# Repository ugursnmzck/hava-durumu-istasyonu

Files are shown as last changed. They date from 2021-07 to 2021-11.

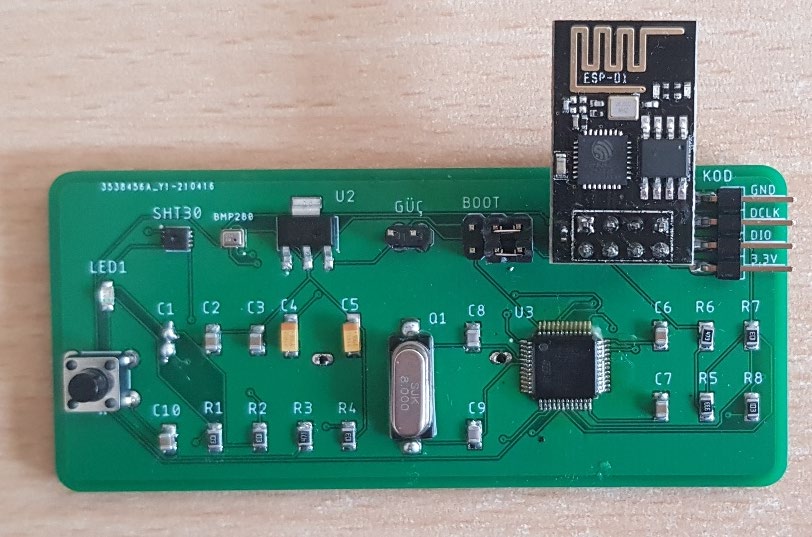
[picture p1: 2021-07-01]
Resimler/lehimli devre.jpg

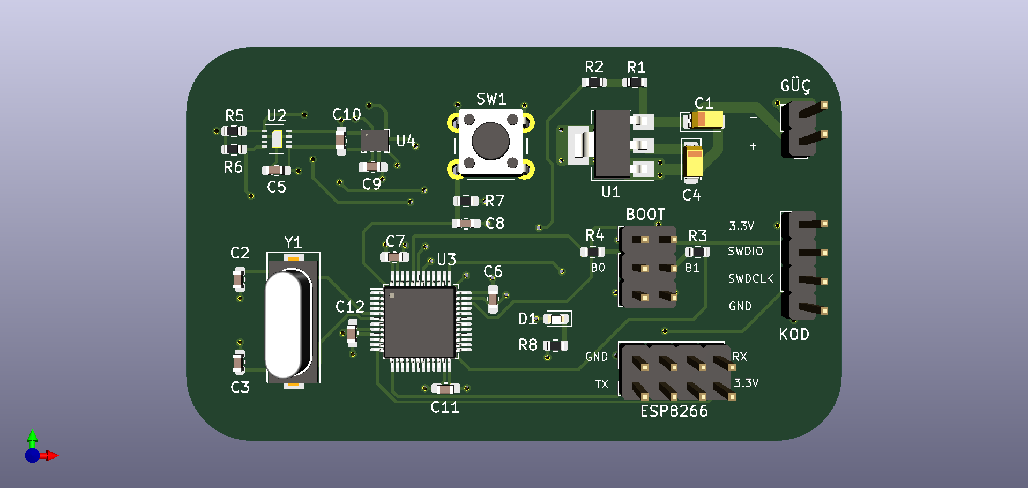
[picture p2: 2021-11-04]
Resimler/Hava_ist_v2.0.png

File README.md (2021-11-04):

# Hava Durumu İstasyonu

V2.0 Yapılan Değişiklikler:
- CAD yazılımı olarak Autodesk Eagle bırakılarak KiCAD kullanıldı.
- Mikroişlemci devresinde dijital güç girişlerinin tamamına filtre kondansatörü eklendi.
- Sıcaklık sensörünün çalışmasını engelleyen filtre kondansatörüne ait bağlantı hatası düzeltildi.
- PCB 4 katmanlı olarak yeniden tasarlandı.

V1.0:

Sıcaklık, nem ve basınç verileri sensörler yardımıyla okunarak kablosuz bir şekilde bilgisayara iletilmektedir.

Sıcaklık ve nem sensörü olarak SHT30, basınç sensörü olarak ise BMP280 kullanılmıştır. Mikrodenetleyici olarak STM32F103C8T6 tercih edilmiştir. Sensör verilerinin yanında pil geirlimi ve gerçek zamanlı saat verisi de mikrodenetleyici ile oluşturulmaktadır. Kablosuz haberleşme için ESP8266-01 modülü tercih edilmiştir. Gömülü sistem kodları C dilinde STM32 CubeIDE üzerinde yazılmıştır. Grafik arayüzü Visual Studio üzerinde C# dili ile hazırlanmıştır. Arayüz tasarımında .NET Framework ve SimpleTCP eklentisi gereklidir.

Gerekli PCB tasarımı Autodesk Eagle ile yapılmıştır.

Proje elektrik elektronik mühendisliği lisans bitirme projesi olarak tasarlanmıştır.

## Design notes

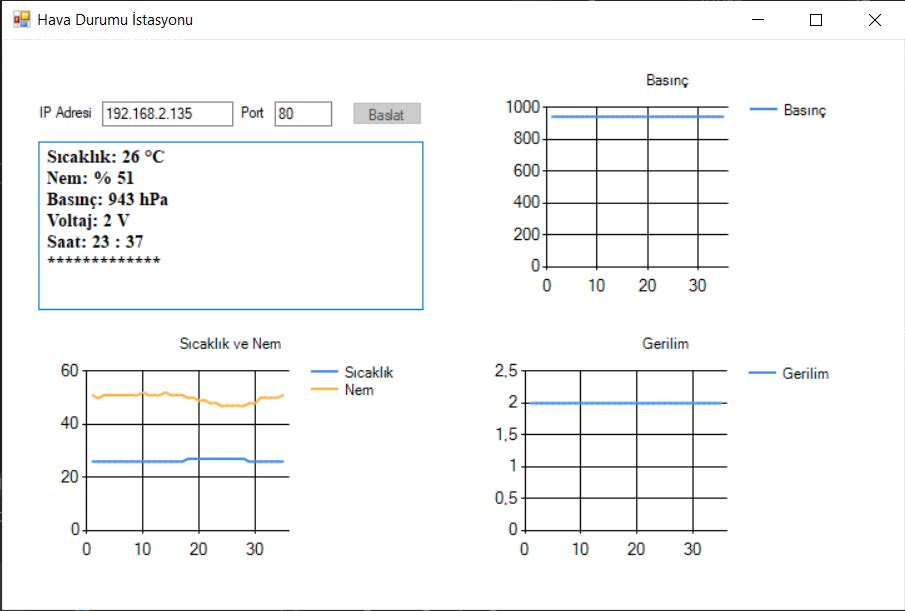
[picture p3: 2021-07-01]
Resimler/grafik arayüzü.jpg

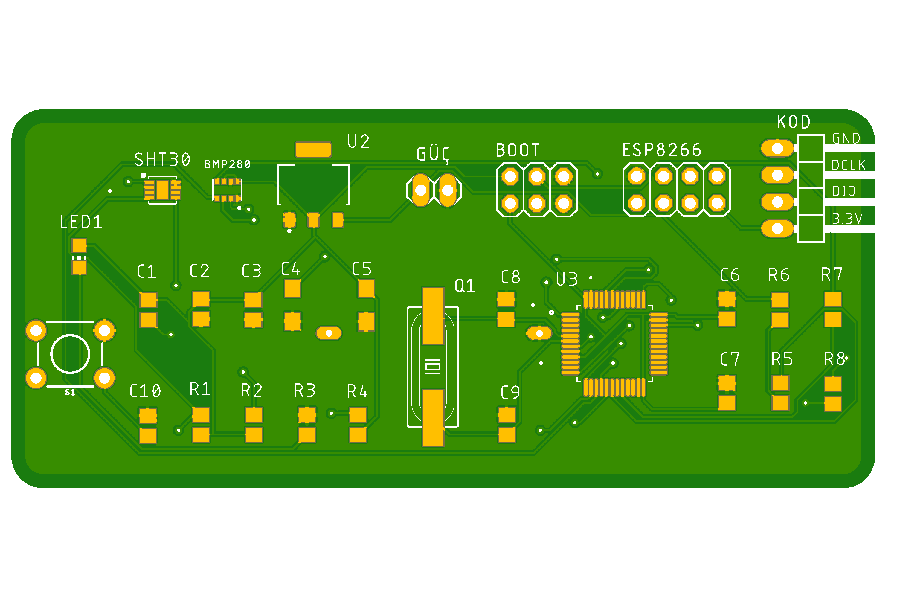
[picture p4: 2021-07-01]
Resimler/V1.0/Hava Durumu İst V1.0.png

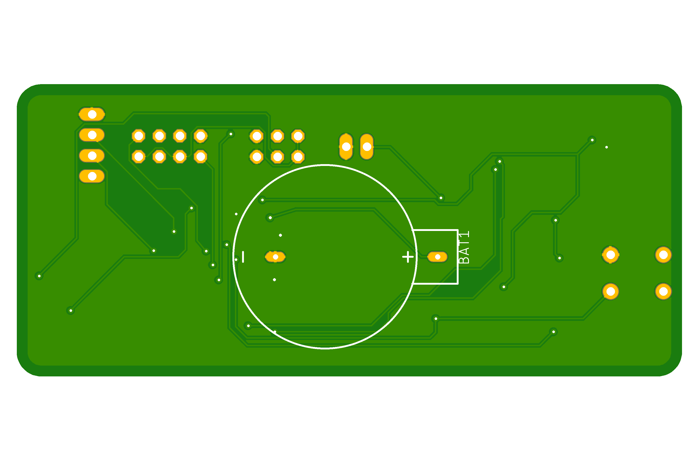
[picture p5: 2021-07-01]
Resimler/V1.0/Hava Durumu İst V1.0arka.png

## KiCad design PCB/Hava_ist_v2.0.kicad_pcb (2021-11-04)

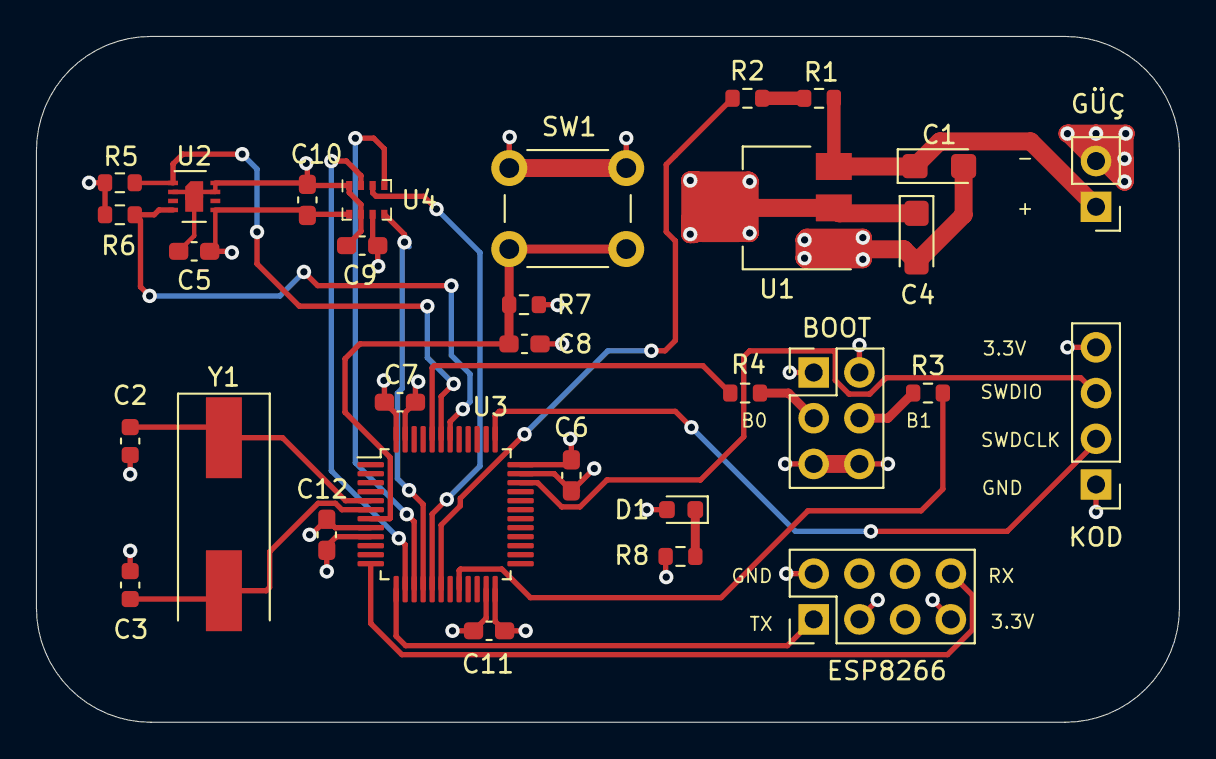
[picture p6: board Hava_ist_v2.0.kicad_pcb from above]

Board: 4 copper layers, 63.5 x 38.1 mm, 31 parts (0 on the bottom side), 23 nets.

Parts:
BOOT: 2x3; PinHeader_2x03_P2.54mm_Vertical
C1, C4: 10 uF; CP_EIA-3216-18_Kemet-A
C2, C3: 12 pF; C_0603_1608Metric
C5, C6, C7, C8, C9, C10, C11, C12: 100 nF; C_0603_1608Metric_Pad1.08x0.95mm_HandSolder
D1: LED; LED_0603_1608Metric
ESP8266: 2x4; PinHeader_2x04_P2.54mm_Vertical
GÜÇ: 1x2; PinHeader_1x02_P2.54mm_Vertical
KOD: 1x4; PinHeader_1x04_P2.54mm_Vertical
R1, R2: 50k; R_0603_1608Metric
R3, R4: 100k; R_0603_1608Metric
R5, R6, R7: 10k; R_0603_1608Metric
R8: 510 R; R_0603_1608Metric
SW1: SW_Push; SW_PUSH_6mm
U1: AMS1117-3.3; SOT-223-3_TabPin2
U2: SHT30-DIS; Sensirion_DFN-8-1EP_2.5x2.5mm_P0.5mm_EP1.1x1.7mm
U3: STM32F103C8Tx; LQFP-48_7x7mm_P0.5mm
U4: BMP280; Bosch_LGA-8_2x2.5mm_P0.65mm_ClockwisePinNumbering
Y1: 8 MHz; Crystal_SMD_HC49-SD

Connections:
+3V3: BOOT.1, BOOT.2, C4.1, C5.2, C6.1, C7.1, C9.1, C10.1, C11.1, C12.1, D1.2, ESP8266.3, ESP8266.7, KOD.4, R5.1, R6.1, R7.1, U1.2, U2.5, U3.9, U3.24, U3.36, U3.48, U4.6, U4.8
/BOOT0: BOOT.3, R4.2
/BOOT1: BOOT.4, R3.2
/CSB_BMP: U3.14, U4.2
/ESP_RX: ESP8266.8, U3.12
/ESP_TX: ESP8266.1, U3.13
/RESET: C8.1, R7.2, SW1.1, U3.7
/SCK_BMP: U3.15, U4.4
/SCL_SHT: R6.2, U2.4, U3.42
/SDA_SHT: R5.2, U2.1, U3.43
/SDI_BMP: U3.17, U4.3
/SDO_BMP: U3.16, U4.5
/SWDCLK: KOD.2, U3.37
/SWDIO: KOD.3, U3.34
/VIN: C1.1, GÜÇ.1, R1.2, U1.3
GND: BOOT.5, BOOT.6, C1.2, C2.2, C3.2, C4.2, C5.1, C6.2, C7.2, C8.2, C9.2, C10.2, C11.2, C12.2, ESP8266.2, GÜÇ.2, KOD.1, R8.1, SW1.2, U1.1, U2.2, U2.7, U2.8, U2.9, U3.8, U3.23, U3.35, U3.47, U4.1, U4.7
unnamed: C2.1, U3.5, Y1.1
unnamed: C3.1, U3.6, Y1.2
unnamed: D1.1, R8.2
unnamed: R1.1, R2.2
unnamed: R2.1, U3.18
unnamed: R3.1, U3.20
unnamed: R4.1, U3.44

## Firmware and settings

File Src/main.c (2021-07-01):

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
/* Includes ------------------------------------------------------------------*/
#include "main.h"

/* USER CODE BEGIN Includes */

#include <stdio.h>
#include "bmp280.h"
#include "ESP8266_HAL.h"
#include "sht30_i2c_drv.h"
#include "UartRingbuffer_multi.h"
#include <stdlib.h>
#include <string.h>

/* USER CODE END Includes */

/* USER CODE BEGIN PD */
#define wifi_uart &huart2
#define pc_uart &huart1
RTC_TimeTypeDef sTime;
/* USER CODE END PD */

ADC_HandleTypeDef hadc1;

I2C_HandleTypeDef hi2c1;

RTC_HandleTypeDef hrtc;

SPI_HandleTypeDef hspi1;

UART_HandleTypeDef huart1;
UART_HandleTypeDef huart2;

void SystemClock_Config(void);
static void MX_GPIO_Init(void);
static void MX_ADC1_Init(void);
static void MX_I2C1_Init(void);
static void MX_RTC_Init(void);
static void MX_SPI1_Init(void);
static void MX_USART2_UART_Init(void);
static void MX_USART1_UART_Init(void);

/* USER CODE BEGIN PFP */
void delay_ms(uint32_t period_ms);
int8_t spi_reg_write(uint8_t cs, uint8_t reg_addr, uint8_t *reg_data, uint16_t length);
int8_t spi_reg_read(uint8_t cs, uint8_t reg_addr, uint8_t *reg_data, uint16_t length);
void print_rslt(const char api_name[], int8_t rslt);
/* USER CODE END PFP */

/**
  * @brief  The application entry point.
  * @retval int
  */
int main(void)
{
  /* USER CODE BEGIN 1 */
	uint8_t gelen_veri[6] = {0};
	float sicaklik = 0;
	float nem      = 0;
	double basinc   = 0;
	float voltaj   = 0;
	int saat     = 0;
	int dakika   = 0;
	char rapor[40];
	char data [80];
	int len = strlen (rapor);
	int8_t rslt;
	    struct bmp280_dev bmp;
	    struct bmp280_config conf;
	    struct bmp280_uncomp_data ucomp_data;
	    //uint32_t pres32, pres64;
	    double pres;
	    bmp.delay_ms = delay_ms;
  /* USER CODE END 1 */

  /* MCU Configuration--------------------------------------------------------*/

  /* Reset of all peripherals, Initializes the Flash interface and the Systick. */
  HAL_Init();

  /* Configure the system clock */
  SystemClock_Config();

  /* Initialize all configured peripherals */
  MX_GPIO_Init();
  MX_ADC1_Init();
  MX_I2C1_Init();
  MX_RTC_Init();
  MX_SPI1_Init();
  MX_USART2_UART_Init();
  MX_USART1_UART_Init();
  /* USER CODE BEGIN 2 */

  HAL_ADC_Start(&hadc1);


  Ringbuf_init();


    	Uart_sendstring("AT+RST\r\n", wifi_uart);
    	Uart_sendstring("RESETTING.", pc_uart);
    	for (int i=0; i<5; i++)
    	{
    		//Uart_sendstring(".", pc_uart);
    		HAL_Delay(1000);
    	}

    	/********* AT **********/
    	Uart_flush(wifi_uart);
    	Uart_sendstring("AT\r\n", wifi_uart);
    	while(!(Wait_for("OK\r\n", wifi_uart)));
    	Uart_sendstring("AT---->OK\n\n", pc_uart);


    	/********* AT+CWMODE=1 **********/
    	Uart_flush(wifi_uart);
    	Uart_sendstring("AT+CWMODE=1\r\n", wifi_uart);
    	while (!(Wait_for("OK\r\n", wifi_uart)));
    	Uart_sendstring("CW MODE---->1\n\n", pc_uart);

    	Uart_flush(wifi_uart);
    	Uart_sendstring("AT+CIPMUX=1\r\n", wifi_uart);
    	while (!(Wait_for("OK\r\n", wifi_uart)));
    	Uart_sendstring("CIPMUX---->OK\n\n", pc_uart);

    	/********* AT+CIPSERVER **********/
    	Uart_flush(wifi_uart);
    	Uart_sendstring("AT+CIPSERVER=1,80\r\n", wifi_uart);
    	while (!(Wait_for("OK\r\n", wifi_uart)));
    	Uart_sendstring("CIPSERVER---->OK\n\n", pc_uart);
    	HAL_Delay(1000);


  	  SHT30_reset();
  	HAL_Delay(1000);
      if(SHT30_Init() == HAL_OK)
          {
    	  sprintf(rapor,"SHT30 yapilandirma tamam.\n");
    	  printf(rapor,"SHT30 yapilandirma tamam.\n");

          }
      else{
    	   sprintf(rapor,"SHT30 yapilandirma hatasi.\n");
    	   printf(rapor,"SHT30 yapilandirma err.\n");
      }

      bmp.dev_id = 0;
           bmp.read = spi_reg_read;
           bmp.write = spi_reg_write;
           bmp.intf = BMP280_SPI_INTF;

          rslt = bmp280_init(&bmp);
          //print_rslt(" bmp280_init durumu", rslt);
          HAL_Delay(250);

          rslt = bmp280_get_config(&conf, &bmp);
          //print_rslt(" bmp280_get_config durumu", rslt);
          HAL_Delay(250);

          conf.filter = BMP280_FILTER_OFF;
          HAL_Delay(250);

          conf.os_pres = BMP280_OS_1X;
          HAL_Delay(250);

          conf.odr = BMP280_ODR_62_5_MS;
          rslt = bmp280_set_config(&conf, &bmp);
          //print_rslt(" bmp280_set_config durumu", rslt);
          HAL_Delay(250);

          /* Always set the power mode after setting the configuration */
          rslt = bmp280_set_power_mode(BMP280_FORCED_MODE, &bmp);
          //print_rslt(" bmp280_set_power_mode durumu", rslt);
          HAL_Delay(250);

  /* USER CODE END 2 */

  /* Infinite loop */
  /* USER CODE BEGIN WHILE */
  while (1)
  {
    /* USER CODE END WHILE */

    /* USER CODE BEGIN 3 */
	  //HAL_Delay(1000);
	  		if(SHT30_Read_Dat(gelen_veri) == HAL_OK)
	  		{
	  			if(SHT30_Dat_To_Float(gelen_veri, &sicaklik, &nem)==0)
	  			{
	  				//sprintf(rapor,"%f,%f,%d,%d,%d,%d",sicaklik,nem,basinc,voltaj,saat,dakika);
	  			}
	  			else
	  			{
	  				printf("crc check fail.\n");
	  			}
	  		}
	  		else
	  		{
	  			printf("read data from sht30 fail.\n");
	  		}
	  		//HAL_Delay(250);

  	  	  /* Reading the raw data from sensor */
          rslt = bmp280_get_uncomp_data(&ucomp_data, &bmp);
          //HAL_Delay(250);

          /* Getting the compensated pressure as floating point value */
          rslt = bmp280_get_comp_pres_double(&pres, ucomp_data.uncomp_press, &bmp);
          basinc=pres/20000;
          //HAL_Delay(1000);


          voltaj = HAL_ADC_GetValue(&hadc1);
          voltaj = voltaj/4096*3.3;
          if (voltaj == 0){
        	  voltaj = 3.3;
          }
          else{}
          //HAL_Delay(100);

          HAL_RTC_GetTime(&hrtc , &sTime , RTC_FORMAT_BIN);
          saat   = sTime.Hours;
          dakika = sTime.Minutes;
          //HAL_Delay(250);

          sprintf(rapor,"%.0f,%.0f,%.0f,%.0f,%d,%d",sicaklik,nem,basinc,voltaj,saat,dakika);
          //HAL_Delay(100);


          sprintf (data, "AT+CIPSEND=%d,%d\r\n", 0, len);
          Uart_sendstring(data, wifi_uart);
          HAL_Delay(1000);
          while (!(Wait_for(">", wifi_uart)));
          Uart_sendstring (rapor, wifi_uart);
          HAL_Delay(1000);
          while (!(Wait_for("SEND OK", wifi_uart)));
          //HAL_Delay(1000);

  }
  /* USER CODE END 3 */
}

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
/* USER CODE BEGIN 4 */

void delay_ms(uint32_t period_ms)
{
    /* Implement the delay routine according to the target machine */
}

int8_t spi_reg_write(uint8_t cs, uint8_t reg_addr, uint8_t *reg_data, uint16_t length)
{

    /* Implement the SPI write routine according to the target machine. */
    return -1;
}

int8_t spi_reg_read(uint8_t cs, uint8_t reg_addr, uint8_t *reg_data, uint16_t length)
{

    /* Implement the SPI read routine according to the target machine. */
    return -1;
}

/* USER CODE END 4 */
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


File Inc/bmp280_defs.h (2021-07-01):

#ifndef __BMP280_DEFS_H__
#define __BMP280_DEFS_H__

/*! CPP guard */
#ifdef __cplusplus
extern "C" {
#endif

/****************************************************************/
/*! @name       Header includes             */
/****************************************************************/
#ifdef __KERNEL__
#include <linux/types.h>
#include <linux/kernel.h>
#else
#include <stdint.h>
#include <stddef.h>
#endif

/****************************************************************/
/*! @name       Common macros               */
/****************************************************************/
#ifdef __KERNEL__
#if !defined(UINT8_C) && !defined(INT8_C)
#define INT8_C(x)   S8_C(x)
#define UINT8_C(x)  U8_C(x)
#endif

#if !defined(UINT16_C) && !defined(INT16_C)
#define INT16_C(x)  S16_C(x)
#define UINT16_C(x) U16_C(x)
#endif

#if !defined(INT32_C) && !defined(UINT32_C)
#define INT32_C(x)  S32_C(x)
#define UINT32_C(x) U32_C(x)
#endif

#if !defined(INT64_C) && !defined(UINT64_C)
#define INT64_C(x)  S64_C(x)
#define UINT64_C(x) U64_C(x)
#endif
#endif

/*! @name C standard macros */
#ifndef NULL
#ifdef __cplusplus
#define NULL 0
#else
#define NULL ((void *) 0)
#endif
#endif

/****************************************************************/
/*! @name       BMP280 Macros               */
/****************************************************************/

/*! @name Macro to disable double precision floating point compensation
 * @note Uncomment the following line to disable it
 */
#ifndef BMP280_DISABLE_DOUBLE_COMPENSATION

/* #define BMP280_DISABLE_DOUBLE_COMPENSATION */
#endif

/*! @name Macro to disable 64bit compensation
 * @note Uncomment the following line to disable it
 */
#ifndef BMP280_DISABLE_64BIT_COMPENSATION

/* #define BMP280_DISABLE_64BIT_COMPENSATION */
#endif

/*! @name Interface selection macros */
#define BMP280_SPI_INTF                      UINT8_C(1)
#define BMP280_I2C_INTF                      UINT8_C(0)

/*! @name Return codes */
/*! @name Success code*/
#define BMP280_OK                            INT8_C(0)
#define BMP280_BOND_WIRE_OK                  INT8_C(0)

/*! @name Error codes */
#define BMP280_E_NULL_PTR                    INT8_C(-1)
#define BMP280_E_DEV_NOT_FOUND               INT8_C(-2)
#define BMP280_E_INVALID_LEN                 INT8_C(-3)
#define BMP280_E_COMM_FAIL                   INT8_C(-4)
#define BMP280_E_INVALID_MODE                INT8_C(-5)
#define BMP280_E_BOND_WIRE                   INT8_C(-6)
#define BMP280_E_IMPLAUS_TEMP                INT8_C(-7)
#define BMP280_E_IMPLAUS_PRESS               INT8_C(-8)
#define BMP280_E_CAL_PARAM_RANGE             INT8_C(-9)
#define BMP280_E_UNCOMP_TEMP_RANGE           INT8_C(-10)
#define BMP280_E_UNCOMP_PRES_RANGE           INT8_C(-11)
#define BMP280_E_UNCOMP_TEMP_AND_PRESS_RANGE INT8_C(-12)
#define BMP280_E_UNCOMP_DATA_CALC            INT8_C(-13)
#define BMP280_E_32BIT_COMP_TEMP             INT8_C(-14)
#define BMP280_E_32BIT_COMP_PRESS            INT8_C(-15)
#define BMP280_E_64BIT_COMP_PRESS            INT8_C(-16)
#define BMP280_E_DOUBLE_COMP_TEMP            INT8_C(-17)
#define BMP280_E_DOUBLE_COMP_PRESS           INT8_C(-18)

/*! @name Chip IDs for samples and mass production parts */
#define BMP280_CHIP_ID1                      UINT8_C(0x56)
#define BMP280_CHIP_ID2                      UINT8_C(0x57)
#define BMP280_CHIP_ID3                      UINT8_C(0x58)

/*! @name I2C addresses */
#define BMP280_I2C_ADDR_PRIM                 UINT8_C(0x76)
#define BMP280_I2C_ADDR_SEC                  UINT8_C(0x77)
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

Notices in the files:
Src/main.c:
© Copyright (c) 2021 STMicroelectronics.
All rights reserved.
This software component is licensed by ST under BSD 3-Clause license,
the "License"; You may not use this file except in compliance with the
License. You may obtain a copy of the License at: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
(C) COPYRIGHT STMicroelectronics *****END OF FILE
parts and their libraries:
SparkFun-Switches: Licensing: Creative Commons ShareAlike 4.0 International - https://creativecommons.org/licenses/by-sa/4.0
